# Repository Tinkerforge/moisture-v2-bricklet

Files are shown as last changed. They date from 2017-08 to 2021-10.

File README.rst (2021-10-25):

Moisture Bricklet 2.0
=====================

**The development of this Bricklet was stopped.**

This repository contains the firmware source code and the hardware design
files. The documentation generator configs can be found at
https://github.com/Tinkerforge/generators

Repository Content
------------------

software/:
 * examples/: Examples for all supported languages
 * build/: Compiled files
 * src/: Source code of firmware
 * Makefile: Makefile to build project

hardware/:
 * Contains KiCad project files and additionally schematics as PDF

datasheets/:
 * Contains datasheets for sensors and complex ICs that are used

Hardware
--------

The hardware is designed with the open source EDA Suite KiCad
(http://www.kicad.org). Before you are able to open the files,
you have to install the Tinkerforge kicad-libraries
(https://github.com/Tinkerforge/kicad-libraries). You can either clone
them directly in hardware/ or clone them in a separate folder and
symlink them into hardware/
(ln -s kicad_path/kicad-libraries project_path/hardware). After that you
can open the .pro file in hardware/ with KiCad and from there view and
modify the schematics and the PCB layout.

Software
--------

If you want to do your own Brick/Bricklet firmware development we highly
recommend that you use our build environment setup script and read the
tutorial (https://www.tinkerforge.com/en/doc/Tutorials/Tutorial_Build_Environment/Tutorial.html).

To compile the C code we recommend you to install the newest GNU Arm Embedded
Toolchain (https://launchpad.net/gcc-arm-embedded/+download).
You also need to install bricklib2 (https://github.com/Tinkerforge/bricklib2).

You can either clone it directly in software/src/ or clone it in a
separate folder and symlink it into software/src/
(ln -s bricklib_path/bricklib2 project_path/software/src/). Finally make sure to
have CMake installed (http://www.cmake.org/cmake/resources/software.html).

After that you can build the firmware by invoking make in software/.
The firmware (.zbin) can then be found in software/build/ and uploaded
with brickv (click button "Flashing" on start screen).

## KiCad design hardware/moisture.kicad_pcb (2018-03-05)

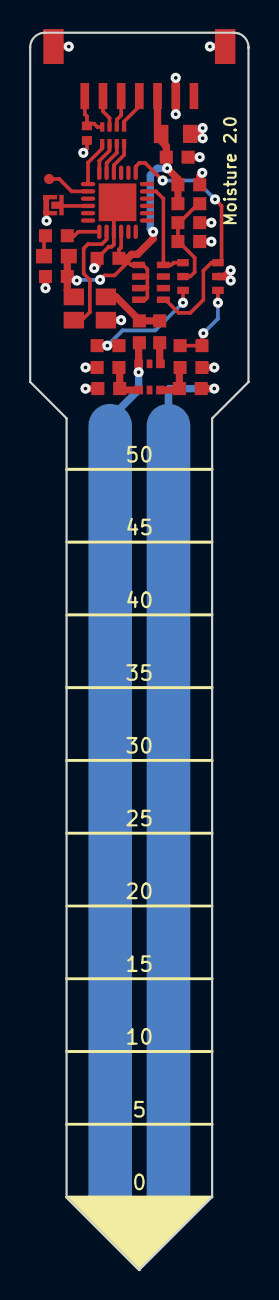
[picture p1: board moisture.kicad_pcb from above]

Board: 2 copper layers, 15.0 x 85.0 mm, 30 parts (2 on the bottom side), 25 nets.

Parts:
C1: 10uF; C0805
C2: TBD; C0402F
C3, C5, C6: 1uF; C0603F
C4, C7, C8: 100nF; C0603F
C9, C10: TBD; C0603F
D1: blue; D0603E
D2: BAT54TW; SOT363
L1: INDUCT; R0603F
P1: CON-SENSOR2
P2: DEBUG; DEBUG_PAD
P3: BOOT; SolderJumper
Q1: Oscillator; CRYSTAL_3225_4
R1, R3, R6: 1k; R0603F
R2, R5: 68; R0603F
R4, R7: DNP; R0603F
RP1: TBD; 4X0402
RP2: 1k; 4X0603
U1: XMC1XXX24; QFN24-4x4mm-0.5mm
U2: MCP3425; SOT23-6
VAL: WEEE_7mm
VAL#2: CE_5mm

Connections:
CLK-EN: Q1.1, U1.8
GND: C1.1, C2.1, C3.1, C4.2, C5.2, C6.2, C7.2, C8.2, C9.2, C10.2, P1.2, P1.EP, P3.1, Q1.2, R4.1, R7.1, U1.9, U1.EXP, U2.2
unnamed: C2.2, P1.7, RP1.4
unnamed: C6.1, C7.1, L1.2, U2.5
unnamed: C9.1, D2.6, R3.2
unnamed: C10.1, D2.4, R6.2
unnamed: D1.2, R1.2
unnamed: D2.1, R2.1
unnamed: P1.4, RP1.1
unnamed: P1.5, RP1.2
unnamed: P1.6, RP1.3
unnamed: P2.1, U1.2
unnamed: P3.2, U1.4
unnamed: Q1.3, R2.2, R5.2
unnamed: R1.1, U1.7
unnamed: R3.1, R4.2, U2.1
unnamed: R6.1, R7.2, U2.6
S-CLK: RP1.7, U1.23
S-CS: RP1.8, U1.22
S-MISO: RP1.5, U1.1
S-MOSI: RP1.6, U1.24
SCL: RP2.8, U1.19, U2.3
SDA: RP2.5, U1.17, U2.4
SIG: D2.3, R5.1
VCC: C1.2, C3.2, C4.1, C5.1, C8.1, D1.1, L1.1, P1.3, Q1.4, RP2.1, RP2.2, RP2.3, RP2.4, U1.10

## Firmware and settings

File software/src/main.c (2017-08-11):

/* moisture-v2-bricklet
 * Copyright (C) 2017 Olaf Lüke <olaf@tinkerforge.com>
 *
 * main.c: Initialization for Moisture V2 Bricklet
 *
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
 * You should have received a copy of the GNU Lesser General Public
 * License along with this library; if not, write to the
 * Free Software Foundation, Inc., 59 Temple Place - Suite 330,
 * Boston, MA 02111-1307, USA.
 */

#include <stdio.h>
#include <stdbool.h>

#include "configs/config.h"

#include "bricklib2/bootloader/bootloader.h"
#include "bricklib2/hal/system_timer/system_timer.h"
#include "bricklib2/logging/logging.h"
#include "communication.h"
#include "mcp3425.h"

MCP3425 mcp3425;

int main(void) {
	logging_init();
	logd("Start Moisture V2 Bricklet\n\r");

	// Enable 80MHz oscillator
	XMC_GPIO_CONFIG_t oscillator_enable_pin;
	oscillator_enable_pin.mode = XMC_GPIO_MODE_OUTPUT_PUSH_PULL;
	oscillator_enable_pin.output_level = XMC_GPIO_OUTPUT_LEVEL_HIGH;
	XMC_GPIO_Init(OSCILLATOR_ENABLE_PIN, &oscillator_enable_pin);

	mcp3425_init(&mcp3425);
	communication_init();

	while(true) {
		bootloader_tick();
		mcp3425_tick(&mcp3425);
//		communication_tick();
	}
}

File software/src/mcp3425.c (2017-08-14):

/* moisture-v2-bricklet
 * Copyright (C) 2017 Olaf Lüke <olaf@tinkerforge.com>
 *
 * mcp3425.c: MCP3425 driver
 *
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
 * You should have received a copy of the GNU Lesser General Public
 * License along with this library; if not, write to the
 * Free Software Foundation, Inc., 59 Temple Place - Suite 330,
 * Boston, MA 02111-1307, USA.
 */

#include "mcp3425.h"

#include "configs/config_mcp3425.h"
#include "bricklib2/hal/system_timer/system_timer.h"
#include "bricklib2/hal/i2c_fifo/i2c_fifo.h"

#include "bricklib2/logging/logging.h"

void mcp3425_init(MCP3425 *mcp3425) {
	mcp3425->i2c_fifo.baudrate         = MCP3425_I2C_BAUDRATE;
	mcp3425->i2c_fifo.address          = MCP3425_I2C_ADDRESS;
	mcp3425->i2c_fifo.i2c              = MCP3425_I2C;

	mcp3425->i2c_fifo.scl_port         = MCP3425_SCL_PORT;
	mcp3425->i2c_fifo.scl_pin          = MCP3425_SCL_PIN;
	mcp3425->i2c_fifo.scl_mode         = MCP3425_SCL_PIN_MODE;
	mcp3425->i2c_fifo.scl_input        = MCP3425_SCL_INPUT;
	mcp3425->i2c_fifo.scl_source       = MCP3425_SCL_SOURCE;
	mcp3425->i2c_fifo.scl_fifo_size    = MCP3425_SCL_FIFO_SIZE;
	mcp3425->i2c_fifo.scl_fifo_pointer = MCP3425_SCL_FIFO_POINTER;

	mcp3425->i2c_fifo.sda_port         = MCP3425_SDA_PORT;
	mcp3425->i2c_fifo.sda_pin          = MCP3425_SDA_PIN;
	mcp3425->i2c_fifo.sda_mode         = MCP3425_SDA_PIN_MODE;
	mcp3425->i2c_fifo.sda_input        = MCP3425_SDA_INPUT;
	mcp3425->i2c_fifo.sda_source       = MCP3425_SDA_SOURCE;
	mcp3425->i2c_fifo.sda_fifo_size    = MCP3425_SDA_FIFO_SIZE;
	mcp3425->i2c_fifo.sda_fifo_pointer = MCP3425_SDA_FIFO_POINTER;

	i2c_fifo_init(&mcp3425->i2c_fifo);

	mcp3425->configuration.bit.rdy               = 0;
	mcp3425->configuration.bit.channel_selection = 0;
	mcp3425->configuration.bit.conversion_mode   = MCP3425_CONF_CONVERSION_MODE_CONTINUOUS;
	mcp3425->configuration.bit.sample_rate       = MCP3425_CONF_SAMPLE_RATE_15SPS;
	mcp3425->configuration.bit.gain              = MCP3425_CONF_GAIN_8X;

	system_timer_sleep_ms(100);

	logd("MCP3425 config: %d\n\r", mcp3425->configuration.data);
	i2c_fifo_write_direct(&mcp3425->i2c_fifo, 1, &mcp3425->configuration.data, true);
}

void mcp3425_tick(MCP3425 *mcp3425) {
	I2CFifoState state = i2c_fifo_next_state(&mcp3425->i2c_fifo);

	if(state & I2C_FIFO_STATE_ERROR) {
		loge("MCP3425 I2C error: %d\n\r", state);
		mcp3425_init(mcp3425);
		return;
	}

	switch(state) {
		case I2C_FIFO_STATE_READ_DIRECT_READY: {
			uint8_t buffer[16];
			uint8_t length = i2c_fifo_read_fifo(&mcp3425->i2c_fifo, buffer, 16);
			if(length != 3) {
				loge("MCP3425 I2C unexpected read length : %d\n\r", length);
				mcp3425_init(mcp3425);
				break;
			}

			int16_t value = (buffer[0] << 8) | buffer[1];
			logd("value: %d\n\r", value);

		} __attribute__((fallthrough));
		case I2C_FIFO_STATE_WRITE_DIRECT_READY:
		case I2C_FIFO_STATE_IDLE: {
			i2c_fifo_read_direct(&mcp3425->i2c_fifo, 3);
			break;
		}

		default: {
			// If we end up in a ready state that we don't handle, something went wrong
			if(state & I2C_FIFO_STATE_READY) {
				loge("MCP3425 I2C unrecognized ready state : %d\n\r", state);
				mcp3425_init(mcp3425);
			}
			return;
		}
	}
}

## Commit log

2017-07-11 add hardware files for new moisture prototype
    [moisture.kicad_pcb, moisture.sch]
2017-08-01 Add 3d information (fam)
    [moisture.kicad_pcb]
2017-08-11 Initial software commit
    Current state: Stub implementation of MCP3425 driver that reads ADC value and prints it
    [cmake_config_custom.txt]
2017-08-14 Use fallthrough attribute to not get wrong GCC warning
    [mcp3425.c]
2018-02-20 Cleanup KiCad libraries config
    Ensure LibDir=kicad-libraries and LibName1=tinkerforge.
    Remove special library.
2018-03-05 change footprints
    [moisture.kicad_pcb, moisture.sch]
2018-05-14 Fix kicad-libraries name
2021-10-25 Update KiCad link
    https://www.kicad.org/blog/2021/10/Avoid-links-to-former-kicad-domain/

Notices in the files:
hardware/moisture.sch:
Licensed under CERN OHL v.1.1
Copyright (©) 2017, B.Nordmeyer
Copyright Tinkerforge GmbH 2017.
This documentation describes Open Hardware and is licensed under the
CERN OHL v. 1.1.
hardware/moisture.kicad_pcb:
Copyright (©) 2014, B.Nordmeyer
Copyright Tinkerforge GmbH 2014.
